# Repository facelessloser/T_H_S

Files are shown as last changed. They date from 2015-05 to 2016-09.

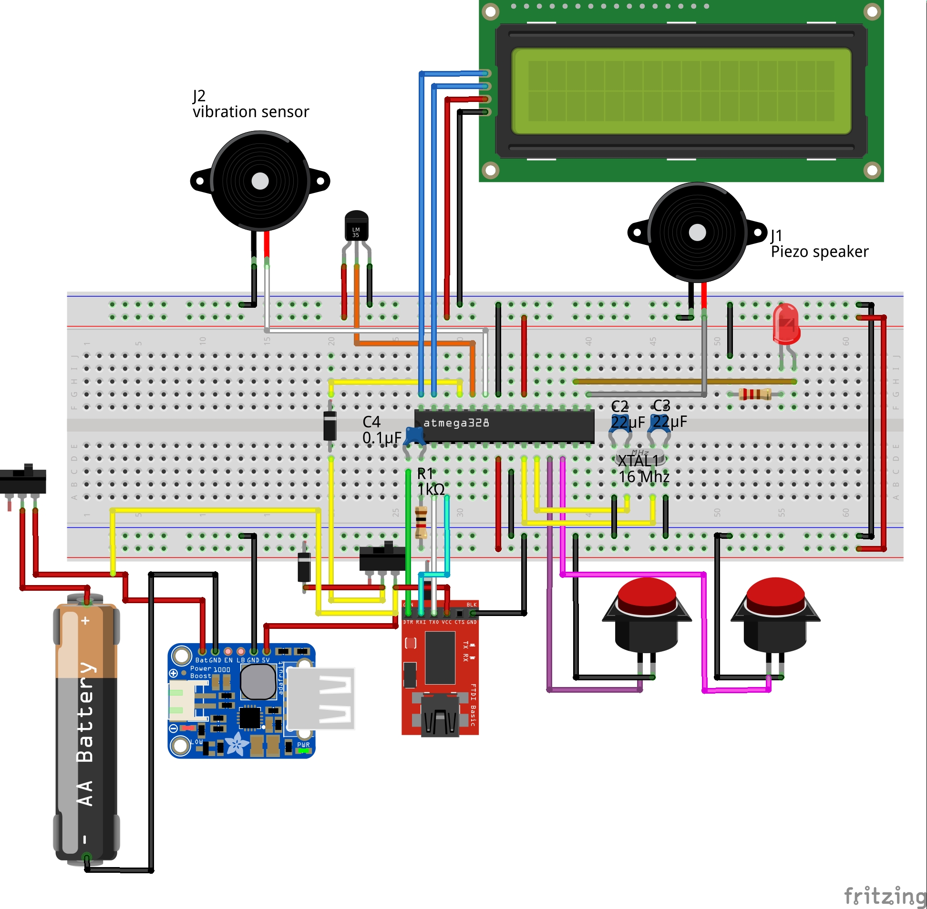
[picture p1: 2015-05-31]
fritzing/T_H_S_bb.jpg

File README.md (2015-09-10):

# T_H_S

https://facelesstech.files.wordpress.com/2015/07/main_ths2.jpg

Low cost open source heart rate and body temperature monitor

Blog post can be found here

https://facelesstech.wordpress.com/2015/07/31/temp_heart_sensor/

Hackaday.io post can be found here 

https://hackaday.io/project/4910-ths

Video can be found here 

https://youtu.be/P-qDKN8uHOM

https://www.youtube.com/watch?v=heoFKFPPkZ0

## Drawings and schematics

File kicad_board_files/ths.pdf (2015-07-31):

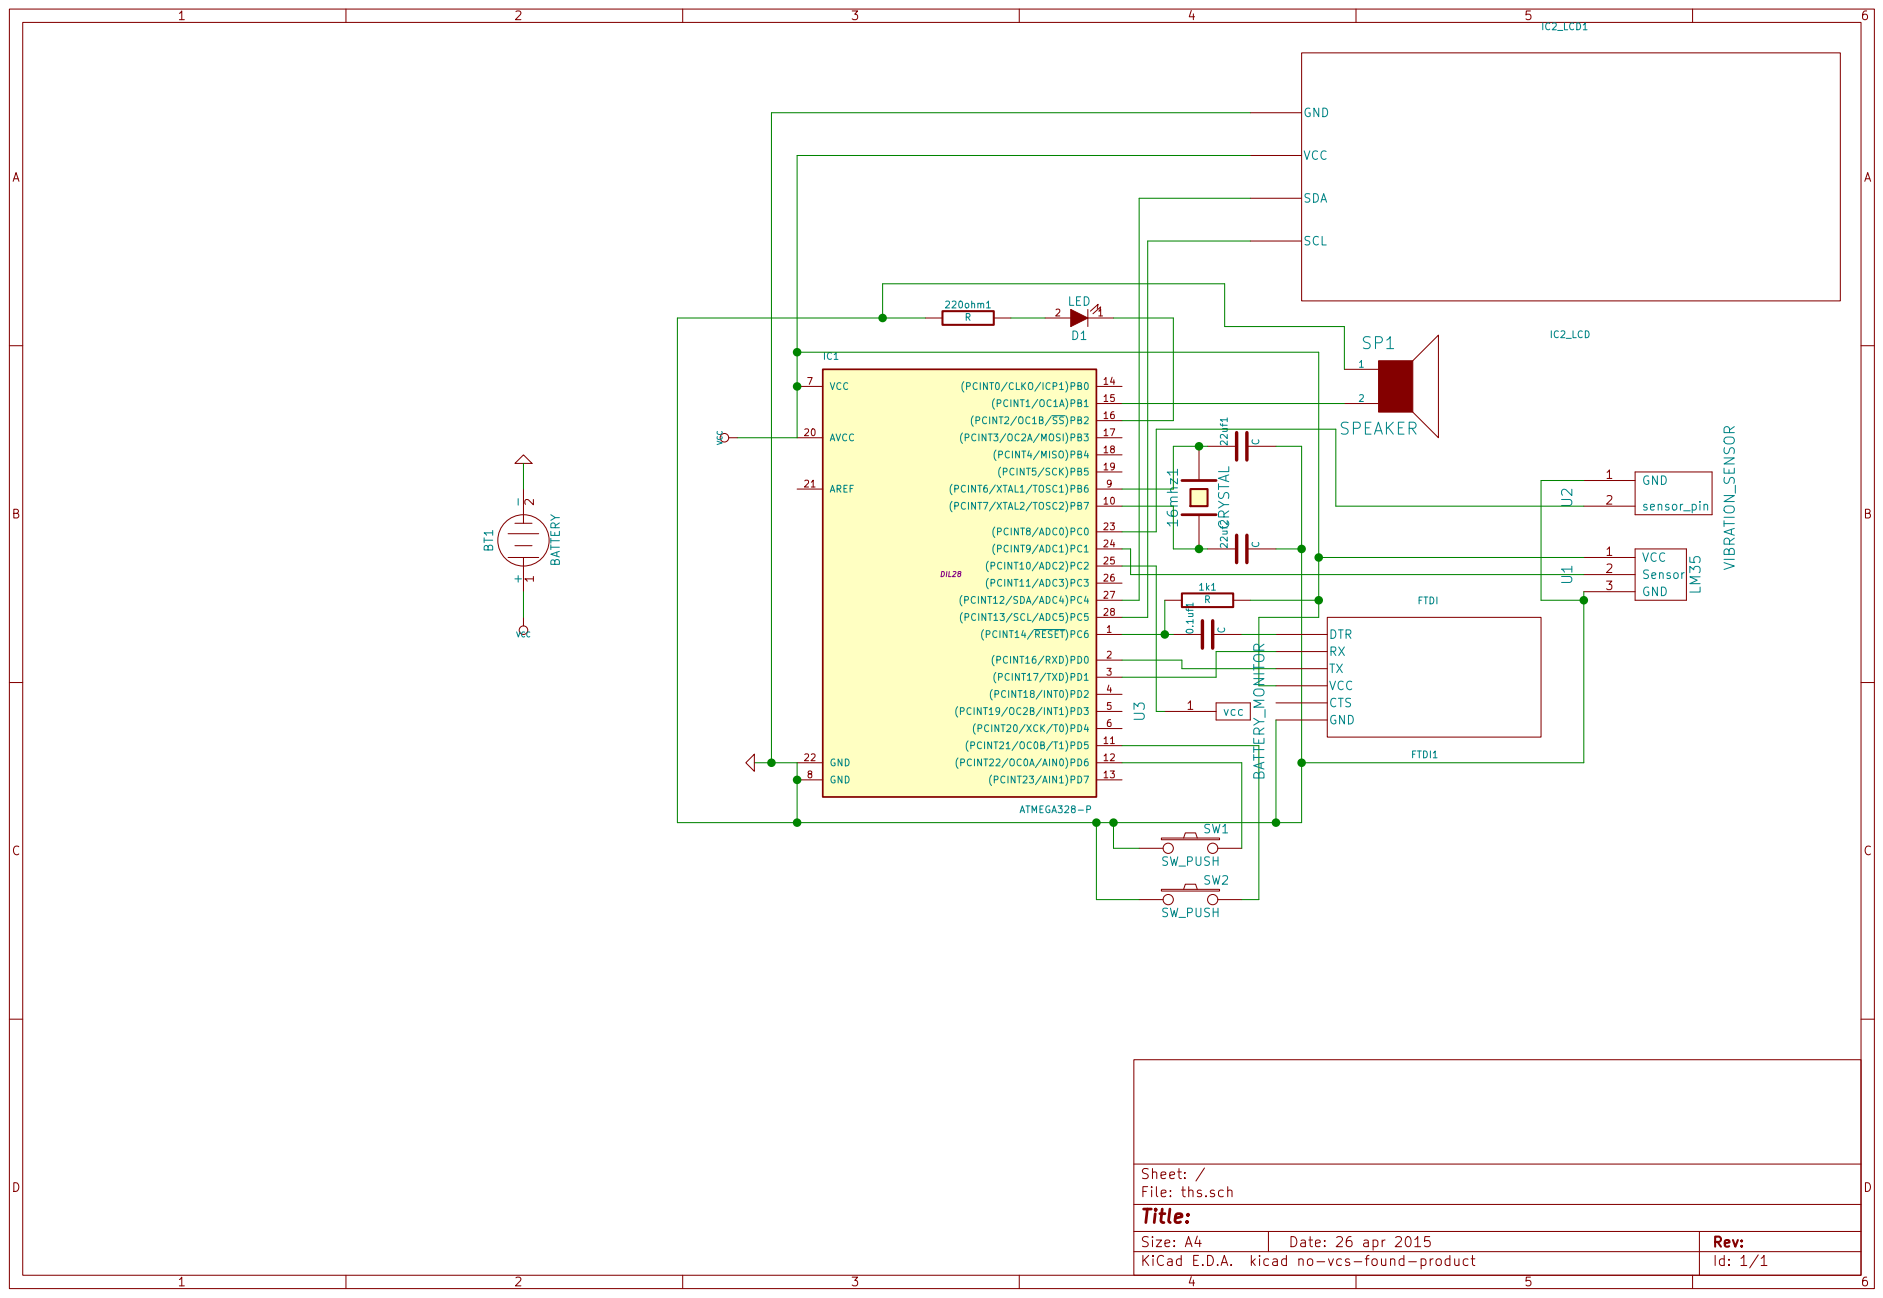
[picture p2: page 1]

Id: 1/1 Title: File: ths.sch Sheet: /

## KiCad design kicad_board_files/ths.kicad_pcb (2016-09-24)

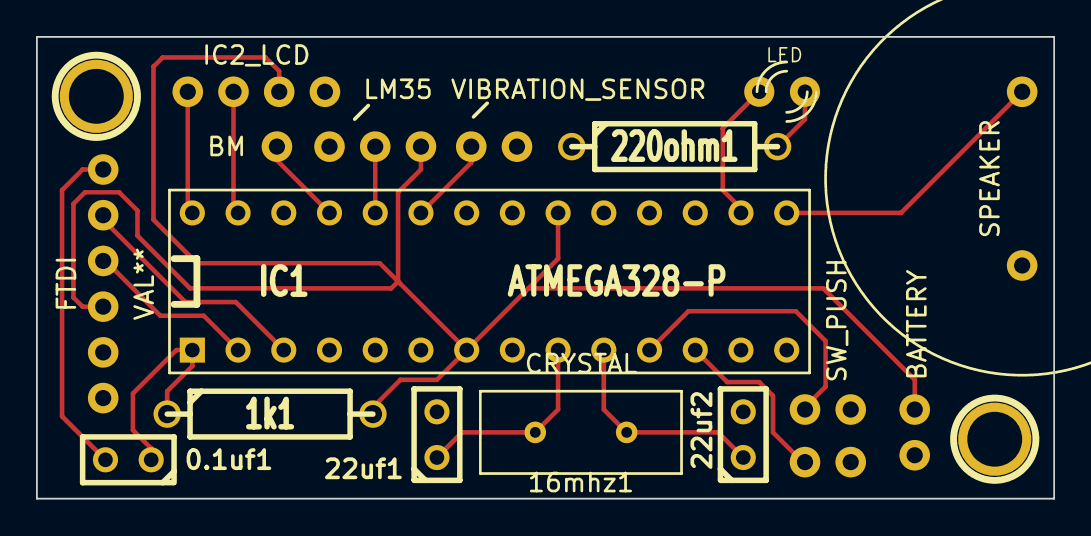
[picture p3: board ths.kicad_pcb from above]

Board: 2 copper layers, 56.5 x 25.7 mm, 20 parts (0 on the bottom side), 15 nets.

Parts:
0.1uf1, 22uf1, 22uf2: C; C1
1PIN, 1PIN#2: P***; 1pin
1k1, 220ohm1: R; R4-5
16mhz1: CRYSTAL; Crystal_custom
BT1: BATTERY; battery_custom
D1: LED; LED_custom
FTDI: VAL**; FTDI
IC1: ATMEGA328-P; atmega328_socket
IC2_LCD1: IC2_LCD; LCD_I2C_Custom
SP1: SPEAKER; speaker_custom
SW1, SW2: SW_PUSH; push_button_custom
U1: LM35
U2: VIBRATION_SENSOR; vibration_sensor
U3: BM; battery_monitor
VAL: OSH_final_silks_back

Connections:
GND: 22uf1.2, 22uf2.2, 220ohm1.1, BT1.2, IC1.8, IC1.22, IC2_LCD1.1, SP1.1, SW1.1, SW2.1, U1.3, U2.1
unnamed: D1.1, IC1.16
unnamed: 220ohm1.2, D1.2
unnamed: IC1.15, SP1.2
unnamed: IC1.11, SW2.2
unnamed: IC1.23, U2.2
unnamed: IC1.25, U3.1
unnamed: IC1.12, SW1.2
unnamed: IC1.24, U1.2
unnamed: 16mhz1.1, 22uf2.1, IC1.10
unnamed: IC1.27, IC2_LCD1.3
unnamed: IC1.28, IC2_LCD1.4
unnamed: 16mhz1.2, 22uf1.1, IC1.9
unnamed: 0.1uf1.1, 1k1.1, IC1.1
VCC: 1k1.2, BT1.1, IC1.7, IC1.20, IC2_LCD1.2, U1.1

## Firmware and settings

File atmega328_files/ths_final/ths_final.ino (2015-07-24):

#include <rtttl.h>
#include <Wire.h> 
#include <LiquidCrystal_I2C.h>
LiquidCrystal_I2C lcd(0x27,16,2);  // set the LCD address to 0x27 for a 16 chars and 2 line display

const int ledBeat = 10; // Led connected to pin 10
const int heartSensor = A0; // Piezo sensor connected to pin A0
int tempPin = A1; // LM35 connected to pin A1
//int tempPin = analogRead(A1); // LM35 connected to pin A1
float tempRead; // Read the LM35 values
int tempRead_c; // Read LM35 C
int tempRead_f; // Read LM35 F 
int heartrate; // Read heart rate sensor

char bufTempC[30]; // Buffer for sending temp data
char bufHeart[30]; // Buffer for sending heart rate data

int threshold = 10; // Threshold for the piezo sensor 
int oldvalue = 0; // Old value for piezo sensor
int newvalue = 0; // New value for piezo sensor
int cnt = 0; // Used for timing 
int timings[16]; // Timing values for the piezo sensor

int firstRun = 1; // Tells it to run the splashscreen

int toggleLedPiezo;
int toggleCtoF = 1;

// Wait time for the millis timers
unsigned long oldmillis = 0;
unsigned long newmillis = 0;
unsigned long waitUntilHeart = 10;
long previousMillisHeart = 0;

int fullBattery = 880; // Battery max value
int emptyBattery = 300; // Battery min value
int batteryPercent; // Batttery percent

// Button one 
const int button_one = 6; // Button set to pin 5
unsigned long time_button_one = 0; // the last time the output pin was toggled
unsigned long debounce_one = 200; // the debounce time, increase if the output flickers
int reading_button_one; // the current reading from the input pin
int previous_button_one = HIGH; // the previous reading from the input pin

// Button two
const int button_two = 5; // Button set to pin 5
unsigned long time_button_two = 0; // the last time the output pin was toggled
unsigned long debounce_two = 200; // the debounce time, increase if the output flickers
int reading_button_two; // the current reading from the input pin
int previous_button_two = HIGH; // the previous reading from the input pin

// Speaker stuff
int pinSpeaker = 9;  // Speaker pin 9 
const int octave = 0;  // The octave set for the player
const char heartBeat[] PROGMEM ="heartBeat:16e"; // Makes the heart beat sound
Rtttl player;  // Song player

uint8_t heart[8] = {0x0, 0xa, 0x1f, 0x1f, 0xe, 0x4, 0x0, 0x0}; // Custom char heart
uint8_t temp[8] = {0x4, 0xa, 0xa, 0xa, 0x11, 0x1f, 0x1f, 0xe}; // Custom char temp 
uint8_t temp_c[8] = {0x8, 0xf4, 0x8, 0x43, 0x4, 0x4, 0x43, 0x0}; // Custom char degrees c
uint8_t temp_f[8] = {0x8, 0xf4, 0x8, 0x7, 0x4, 0x7, 0x4, 0x4}; // Custom char degrees f
uint8_t battery[8] = {0xe, 0x11, 0x11, 0x11, 0x1f, 0x1f, 0x1f, 0x1f}; // Custom char battery
uint8_t charging[8] = {0x4, 0x4, 0xe, 0x1f, 0x11, 0x11, 0x1f, 0xa}; // Custom char battery charging


void setup() {
  Serial.begin(9600); // Start serial
  Serial.println("#T_H_S");

  player.begin(pinSpeaker);  // Starts the player

  lcd.init(); // Start up the lcd
  lcd.backlight(); // Turn on the lcd backlight
  lcd.createChar(0, heart); // Custom Char heart
  lcd.createChar(1, temp); // Custom Char temp
  lcd.createChar(2, temp_c); // Custom Char degrees C
  lcd.createChar(3, battery); // Custom Char battery
  lcd.createChar(4, temp_f); // Custom char degrees F
  lcd.createChar(5, charging); // Custom char charging
  lcd.begin(16, 2); // Set up the lcd to have 16 char on 2 lines

  pinMode(ledBeat, OUTPUT); // Set led pin to be output

  pinMode(button_one, INPUT); // Set the button as input
  digitalWrite(button_one, HIGH); // initiate the internal pull up resistor
  pinMode(button_two, INPUT); // Set the button as input
  digitalWrite(button_two, HIGH); // initiate the internal pull up resistor
  }

void splashScreen() {
  lcd.clear(); // Clears the lcd
  digitalWrite(ledBeat, HIGH); // Make LED high
  lcd.setCursor(0,0); // Set cursor to start of the second screen
  lcd.print("#T_H_S"); // Prints to the LCD
  lcd.setCursor(0,1); // Set cursor to start of the second screen
  lcd.print("v0.3"); // Prints to the LCD
  delay(1000);
  firstRun = 0; // Sets firstRun to 0 so it wouldnt run the warmup code again
  lcd.clear(); // Clears the lcd
  lcd.setCursor(0,1);
  lcd.print((char)0); // Print custom heart sign to LCD
  lcd.print(" 0 "); // Prints to the LCD
  lcd.print("bpm "); // Prints to the LCD
}

void playSong(const char * track) { // Takes the song_# pasted from the if statements below
  player.play_P(track, octave);  // Passes the song_# and octave to the player
}

void batteryLoop() {
    int batteryRead = analogRead(A2); // Reads battery pin
    batteryPercent = map(batteryRead, emptyBattery, fullBattery,0 ,100); // Maps the battery percent from high and lows

  if (batteryRead <= 400 ) {
    //Serial.println("Charging");
    lcd.setCursor(10,1); // Set cursor
    lcd.print((char)5); // Print custom battery icon to LCD
    lcd.print("Power"); // Print to the LCD 
    }

  else {

    if (batteryPercent >= 100) {
      lcd.setCursor(11,1); // Set cursor
      }
    else {
      lcd.setCursor(12,1); // Set cursor
      }
    lcd.print((char)3); // Print custom battery icon to LCD
    lcd.print(batteryPercent); // Print to the LCD
    lcd.print("%"); // Print to the LCD
    }
    }

void loop() {
  unsigned long currentMillisHeart = millis();
  // Runs splashscreen
  if (firstRun == 1) {
    splashScreen();
  }

 // ------------- Debound code button one start code -------------
  reading_button_one = digitalRead(button_one);

  if (reading_button_one == HIGH && previous_button_one == LOW && millis() - time_button_one > debounce_one) { 
    time_button_one = millis(); 
    // Do something here
    toggleCtoF ++; // Increments when the button is pressed
    lcd.clear(); // Clears lcd
    lcd.setCursor(0,1); // Set cursor to start of the second screen
    lcd.print((char)0); // Print custom heart sign to LCD
    lcd.print(" "); // Prints to the LCD
    lcd.print(heartrate,DEC); // Prints to the LCD
    lcd.print(" bpm "); // Prints to the LCD
    if (toggleCtoF == 2) {
      toggleCtoF = 0;
      }
  }
  previous_button_one = reading_button_one;
   
 // -------------- Debound code button one end code -------------

 // ------------- Debound code button two start code -------------
  reading_button_two = digitalRead(button_two);

  if (reading_button_two == HIGH && previous_button_two == LOW && millis() - time_button_two > debounce_two) { 
    time_button_two = millis(); 
    // Do something here, button doesnt do anything yet
    toggleLedPiezo ++; // increments when the button is pressed
    if (toggleLedPiezo == 3) { // When it reaches 3 it resets
      toggleLedPiezo = 0; // Resets the button counter
      }
      }
      
  
  previous_button_two = reading_button_two;
   
 // -------------- Debound code button two end code -------------

  //if (millis() >= waitUntil) {
  if (currentMillisHeart - previousMillisHeart > waitUntilHeart) {
    previousMillisHeart = currentMillisHeart;
    oldvalue = newvalue;
    newvalue = 0;
    for(int i=0; i<64; i++){ // Average over 16 measurements
      //newvalue += analogRead(A2);
      newvalue += analogRead(heartSensor);
    }
    newvalue = newvalue/64;
    // find triggering edge
    if(oldvalue<threshold && newvalue>=threshold){ 
      oldmillis = newmillis;
      newmillis = millis();

      // fill in the current time difference in ringbuffer
      timings[cnt%16]= (int)(newmillis-oldmillis); 
      int totalmillis = 0;
      // calculate average of the last 16 time differences
      for(int i=0;i<16;i++){
        totalmillis += timings[i];
      }

      heartrate = 60000/(totalmillis/16); // calculate heart rate
      //Serial.println(heartrate,DEC);
      cnt++;
      if (toggleLedPiezo == 0) { 
        digitalWrite(ledBeat, HIGH); // Make LED high
        playSong(heartBeat); // Play button sound
        }

      if (toggleLedPiezo == 1) {
        playSong(heartBeat);
      }

      if (toggleLedPiezo == 2) {
        digitalWrite(ledBeat, HIGH);
      }

      lcd.clear(); // Clears the lcd
      lcd.setCursor(0,1); // Set cursor to start of the second screen
      lcd.print((char)0); // Print custom heart sign to LCD
      lcd.print(" "); // Prints to the LCD
      lcd.print(heartrate,DEC); // Prints to the LCD
      //Serial.println(heartrate, DEC);
      lcd.print(" bpm "); // Prints to the LCD

    }
      tempRead_c = analogRead(tempPin); // read analog pin to get temp
      tempRead_c = tempRead_c * 0.48828125; // Converts reading to C
      tempRead_f = tempRead_c *9 / 5; // Converts reading to f
      tempRead_f = tempRead_f + 32; // Converts reading to f
      lcd.setCursor(0,0); // Set cursor to start of the second screen
      lcd.print((char)1); // Print custom temp sign to LCD
      lcd.print(" "); // Prints to the LCD
      if (toggleCtoF == 1) {
        lcd.print(tempRead_c); // Prints to the LCD
        sprintf(bufTempC, "#1#");
        sprintf(bufTempC + strlen(bufTempC), "%d", tempRead_c);
        sprintf(bufTempC + strlen(bufTempC), ";");
        //Serial.print(bufTempC);
        lcd.print((char)2); // Print custom temp_c sign to LCD
        }
      else {
        lcd.print(tempRead_f);
        //Serial.println(tempRead_f);
        lcd.print((char)4); // Print custom temp_f sign to LCD
        }
      lcd.print(" "); // Prints to the LCD
      batteryLoop();
    }

    sprintf(bufHeart, "#2#");
    sprintf(bufHeart + strlen(bufHeart), "%d", heartrate, DEC);
    sprintf(bufHeart + strlen(bufHeart), ";");
    //Serial.print(bufHeart);
    digitalWrite(ledBeat, LOW);

  }

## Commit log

2015-04-18 added battery percentage
2015-04-18 added battery icon
2015-04-19 current 19/4/15 breadboard layout
    [T_H_S.fzz]
2015-04-20 added a button just because
    [T_H_S.fzz]
2015-04-21 added the vcc from the battery booster to the switch
    [T_H_S.fzz]
2015-05-04 added a second button but doesnt do anything yet
2015-05-09 added toggle button between f and c for the temp on the display
2015-05-12 Fixed the disappearing BPM when switching between c and f on the temp. Still need to fix the battery status but that can wait
2015-05-13 Fixed that battery icon issus and cleaned up some of the start up code for the splash screen
2015-05-16 Fixed the button to toggle between led and sound for the heart beat
2015-05-31 Added a new switch and some diodes into the design
    [T_H_S.fzz]
2015-06-24 long awaited update, fixed some bugs and added features
    [ths_final.ino]
2015-07-08 Fixed the gurber files so the FTDI and speaker holes are bigger
    [ths-B_Cu.gbl, ths-B_Mask.gbs, ths-B_SilkS.gbo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]
2016-09-24 Added board files
    [ths-B_Cu.gbl, ths-B_Mask.gbs, ths-B_SilkS.gbo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]
